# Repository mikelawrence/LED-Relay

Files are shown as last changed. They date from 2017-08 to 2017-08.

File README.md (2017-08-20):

# LED Relay Replacement PCB
This board was designed to act as a relay for multi-color strip LED lighting on my wife's Harley Tri Glide. The Infineon BTS7008 Dual High-Side Switch provides up to 7.5A per channel. The software allows a quick on-off-on sequence that keeps the LEDs lit after the trike is turned off for a programmable delay time in minutes. In addition to the Stay ON sequence the board also allows programming the amount of time to delay time. Set main.c for instructions on how to issue Stay ON sequence.

There are 4 inputs to the LED Relay board:
* +12V - This should be connected through a fuse to the battery and should remain hot even when the trike is off. All power to the outputs comes from this wire.
* ACC1 - This is +12V when the bike is turned on (ignition).
* ACC2 - This is +12V when the LED lights should be on.
* GND - Chassis and negative terminal of the battery.
The current software turns both outputs on when both ACC1 and ACC2 are at +12V but this can easily be changed to two independent outputs each controlled by its own ACC input. When either ACC1 off the micro-controller enters a low power state waiting for ACC1 to go back to +12V. Note with my current setup ACC2 can never go to +12V without ACC1 also going to +12V.

## Status and Testing
* Rev 2.2 PCB has not been ordered or tested. Since there is only one simple change and my Rev 2.1 was modified to Rev 2.2 I feel confident Rev 2.2 is ready for use.
  * Added ACC1 connection to PD2 on micro-controller. Only PIN2 has full asynchronous edge detection needed for ACC1.
  * You can order parts from Mouser using this [shared BOM](http://www.mouser.com/ProjectManager/ProjectDetail.aspx?AccessID=7477630473). Note LT3014 is not available at Mouser you must get it somewhere else like Digikey.
  * You can order the PCB from OSH Park using this [link](https://oshpark.com/shared_projects/Q2hSPIYz) to OSH Park.
* Rev 2.1 PCB has been ordered from OSH Park, assembled, and tested.
  * Added R12 and R13.
  * Moved ACC connections on micro-controller.
  * Testing complete after modifying to Rev 2.2.
* Rev 2.0 PCB.
  * Converted older design to KiCad.
  * Switched from low-side switch to dual high-side switch.
* Rev 1.0 Existed as another design that was close.

## Board Preview
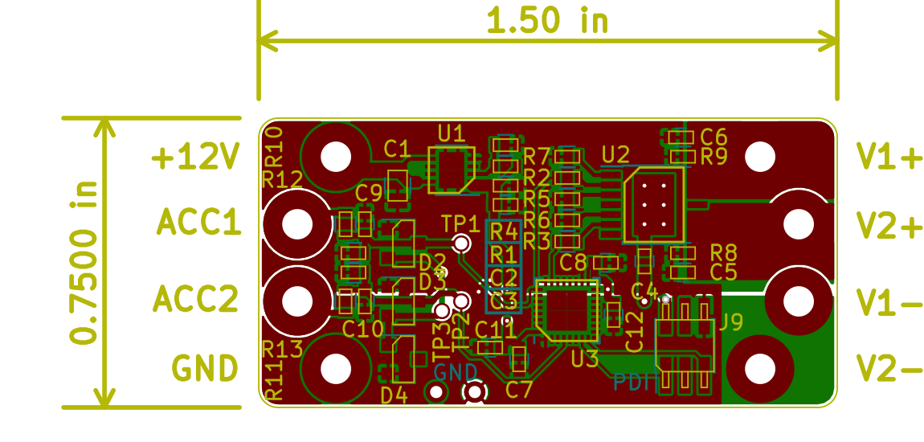
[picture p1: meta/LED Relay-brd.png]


## Notes
* The current usage is only one channel with a typical 4A LED load and maximum of 6A. I have not done any load testing to see how well the board operates with both channels going full bore. The High-Side Switch will shutdown to protect itself if it get too hot.
* When ACC1 is off the XMega8E5 enters an ultra low power mode drawing about 1µA. Add that to the LT3014 linear regulator's quiescent current and this board has standby current of 8µA. In bench testing my first board used 7.8µA at room temperature. Keep in mind this current is likely to double or even triple at higher temperatures but for a motorcycle or car battery this standby current is excellent.
* JP1 must be in place for circuit to work correctly. JP1 is a good scope ground point in testing.
* Assembling the this PCB will require a reflow oven. If you don't have one [Whizoo](http://www.whizoo.com/) sells a nice kit to make your own.
* PCB is designed in [KiCad](http://kicad-pcb.org) which is a great free EDA toolset.

## Software
The microcontroller is a Atmel/Microchip XMega8E5. Software is written in C using the free [Atmel Studio 7](https://www.google.com/search?q=atmel+studio+7). I recommend the Atmel ICE to both debug and program the XMega. Especially since it already has a 50mil PDI connector to plug directly onto the LED Relay board.

## Protection Against the Elements
When mounting on a motorcycle protection against the elements is crucial to longevity so the LED Relay board is thin enough to get 1" adhesive heat shrink on it. Once shrunk the board is well protected and the wires also get some strain relief.

Note I used several different sizes of adhesive heat shrink to get a watertight seal around the wires.
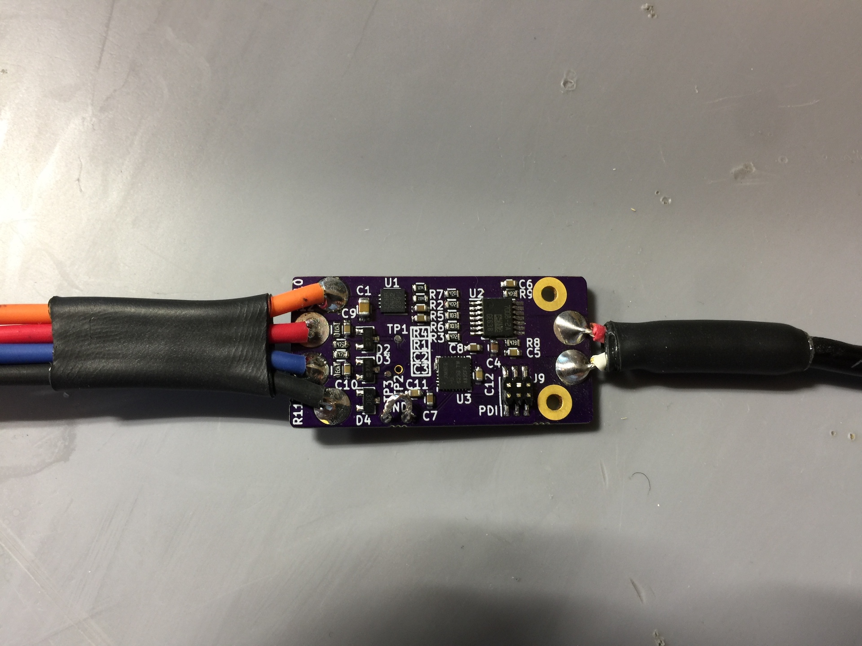
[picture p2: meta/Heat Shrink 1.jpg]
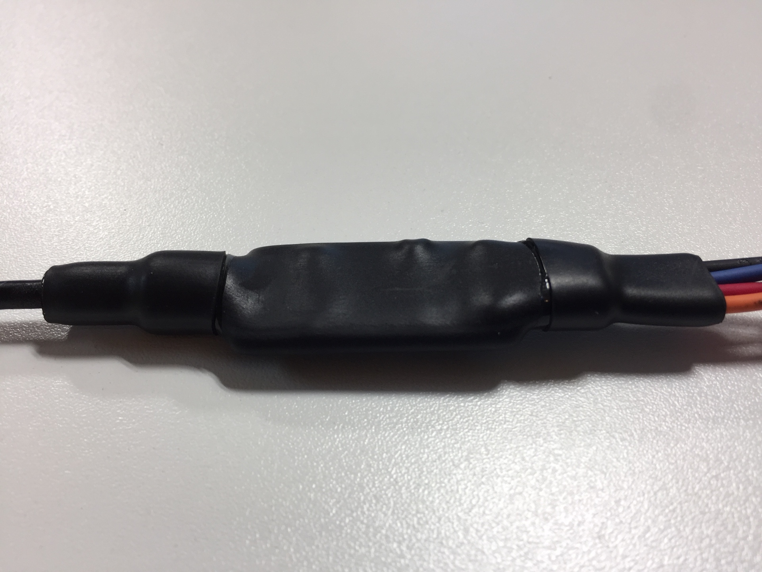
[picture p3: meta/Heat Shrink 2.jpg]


## Final Result
Here is the obligatory end result picture!
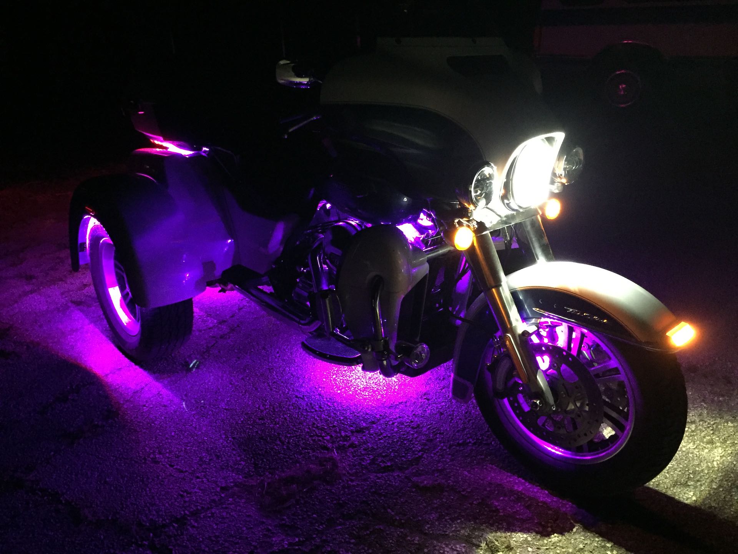
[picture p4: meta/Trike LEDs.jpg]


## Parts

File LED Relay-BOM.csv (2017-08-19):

Qty | Reference | Value | Package | Part Number | Manufacturer | Vendor | Vendor Part Number
6 | C5-C6, C9-C10, C11-C12 | 10nF | 603 | GCM188R72A103KA7D | Murata Electronics | Mouser | 81-GCM188R72A103KA7D
1 | C4 | 68nF | 603 | GCJ188R92A683KA01D | Murata Electronics | Mouser | 81-GCJ188R92A683KA1D
4 | C2-C3, C7-C8 | 0.47uF | 603 | GRM188R71C474KA88 | Murata Electronics | Mouser | 81-GRM188R71C474KA88
1 | C1 | 1uF | 805 | GRJ21BC72A105KE11L | Murata Electronics | Mouser | 81-GRJ21BC72A105KE1L
1 | R7 | 47 | 603 | RC0603FR-0747RL | Yageo | Mouser | 603-RC0603FR-0747RL
2 | R2-R3 | 4.7k | 603 | RC0603JR-074K7L | Yageo | Mouser | 603-RC0603JR-074K7L
2 | R5-R6 | 10k | 603 | RC0603JR-0710KL | Yageo | Mouser | 603-RC0603JR-0710KL
6 | R8-R9, R10-R13 | 47k | 603 | 603-RC0603JR-0747KL | Yageo | Mouser | 603-RC0603JR-0747KL
1 | R4 | 1.27M | 603 | CRCW06031M27FKEA | Vishay | Mouser | 71-CRCW06031M27FKEA
1 | R1 | 2.15M | 603 | CRCW06032M15FKEA | Vishay | Mouser | 71-CRCW06032M15FKEA
2 | D2-D3 | BAT54S | SOT-23 | BAT54S | Nexperia | Mouser | 771-BAT54S-T/R
1 | D1 | SM15T33CA | SMC | SM15T33CA | ST | Mouser | 511-SM15T33CA
1 | D4 | ZRC330 | SOT-23 | ZRC330F01TA | Diodes Inc. | Mouser | 522-ZRC330F01TA
1 | U3 | ATXMEGA8E5-M4U | QFN-32-1EP | ATXMEGA8E5-M4U | Atmel | Mouser | 556-ATXMEGA8E5-M4U
1 | U2 | BTS7008-2EPA | PG-TSDSO-14-22 | BTS70082EPAXUMA1 | Infineon | Mouser | 726-BTS70082EPAXUMA1
1 | U1 | LT3014IDD | DFN-8-1EP | LT3014BHVIDD#PBF | Linear Tech | Digikey | LT3014BHVIDD#PBF-ND
1 | J9 | Header | 6-Pin Header | 20021121-00006C4LF | Amphenol/FCi | Mouser | 649-202112100006C4LF

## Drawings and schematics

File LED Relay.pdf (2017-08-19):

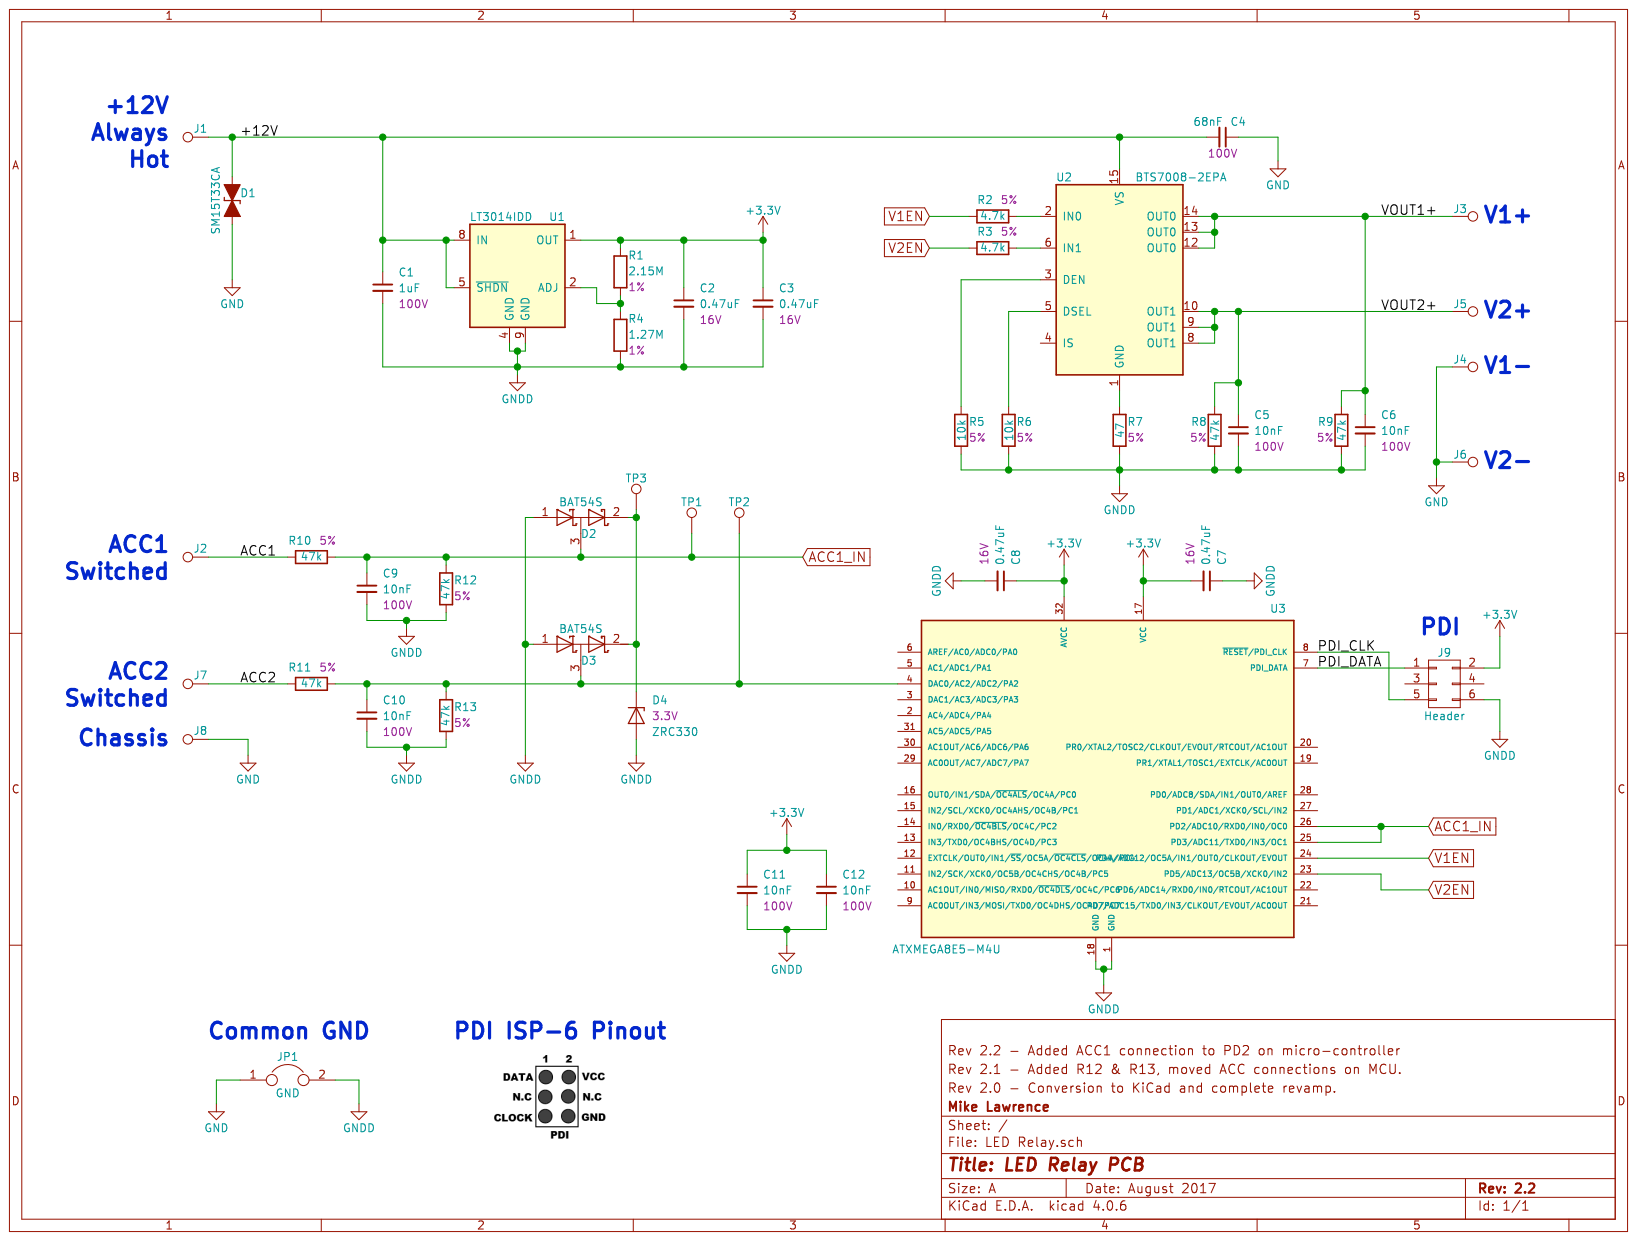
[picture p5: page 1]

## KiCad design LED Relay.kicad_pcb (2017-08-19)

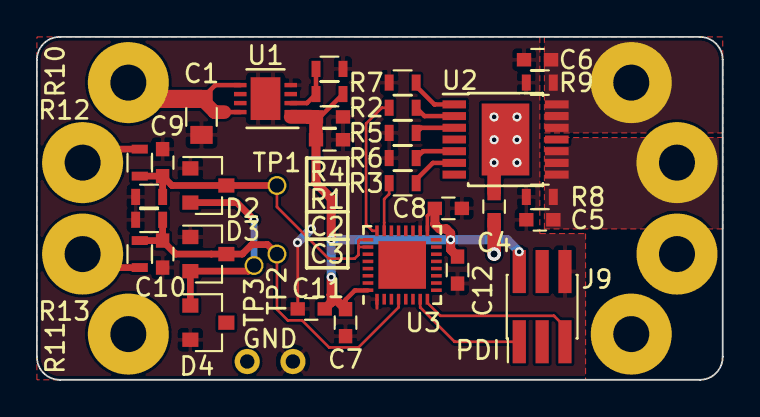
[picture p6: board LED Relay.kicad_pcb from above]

Board: 2 copper layers, 38.1 x 19.1 mm, 45 parts (1 on the bottom side), 21 nets.

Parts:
C1: 1uF; C_0805
C2, C3, C7, C8: 0.47uF; C_0603
C4: 68nF; C_0603
C5, C6, C9, C10, C11, C12: 10nF; C_0603
D1: SM15T33CA; D_SMC_Handsoldering
D2, D3: BAT54S; SOT-23
D4: ZRC330; SOT-23
J1, J2, J3, J4, J5, J6, J7, J8: TEST_1P; SolderWirePad_single_2mmDrill
J9: Header; Pin_Header_Straight_2x03_Pitch1.27mm_SMD
JP1: GND; WireConnection_0.80mmDrill_ThinPad
R1: 2.15M; R_0603
R2, R3: 4.7k; R_0603
R4: 1.27M; R_0603
R5, R6: 10k; R_0603
R7: 47; R_0603
R8, R9, R10, R11, R12, R13: 47k; R_0603
TP1, TP2, TP3: TEST_1P; SolderWirePad_single_0-8mmDrill
U1: LT3014IDD; DFN-8-1EP_3x3mm_Pitch0.5mm
U2: BTS7008-2EPA; Infineon_PG-TSDSO-14-22
U3: ATXMEGA8E5-M4U; QFN-32-1EP_4x4mm_Pitch0.4mm

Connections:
+3V3: C2.1, C3.1, C7.2, C8.1, C11.1, C12.1, J9.2, R1.2, U1.1, U3.17, U3.32
/+12V: C1.1, C4.2, D1.1, J1.1, U1.5, U1.8, U2.15
/ACC1: J2.1, R10.2
/ACC2: J7.1, R11.2
/PDI_CLK: J9.5, U3.8
/PDI_DATA: J9.1, U3.7
/VOUT1+: C6.1, J3.1, R9.2, U2.12, U2.13, U2.14
/VOUT2+: C5.1, J5.1, R8.2, U2.8, U2.9, U2.10
ACC1_IN: C9.1, D2.3, R10.1, R12.2, TP1.1, U3.25, U3.26
GND: C4.1, D1.2, J4.1, J6.1, J8.1, JP1.1
GNDD: C1.2, C2.2, C3.2, C5.2, C6.2, C7.1, C8.2, C9.2, C10.2, C11.2, C12.2, D2.1, D3.1, D4.2, J9.6, JP1.2, R4.1, R5.1, R6.1, R7.1, R8.1, R9.1, R12.1, R13.1, U1.4, U1.9, U3.1, U3.18
unnamed: C10.1, D3.3, R11.1, R13.2, TP2.1, U3.4
unnamed: D2.2, D3.2, D4.1, TP3.1
unnamed: R1.1, R4.2, U1.2
unnamed: R2.1, U2.2
unnamed: R3.1, U2.6
unnamed: R5.2, U2.3
unnamed: R6.2, U2.5
unnamed: R7.2, U2.1
V1EN: R2.2, U3.24
V2EN: R3.2, U3.23

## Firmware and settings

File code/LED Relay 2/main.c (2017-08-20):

/*
 * LED Relay 2.c
 *
 *  The any edge triggered input sense interrupt for ACC1 or ACC2 causes the de-bounce timer to be reset.
 *  Any time this interrupt occurs the input is considered ON which will allow a noisy ON to be recognized 
 *  as ON immediately. If the de-bounce timeout occurs then either the input has stabilized ON or OFF and
 *  and the de-bounce will evaluate the state.
 * Created: 8/12/2017 6:58:33 AM
 * Author : Mike Lawrence
 */ 

/*
 * Stay On sequence = ACC2 ON for less than 3 seconds, ACC2 OFF for less than 3 seconds, ACC1 ON.
 *   Next Power OFF the relay will remain on for programmed timeout (default 30 minute).
 *   This must be done for each power off cycle you want the Outputs to remain on.
 */

/*
 * Programming sequence (Only works within the first 60 seconds of ACC1 turning ON)
 * Flash sequence = ACC2 ON Pulse OFF each less than 3 seconds. The number of ACC2 pulses represents the 
 *   number of 10 minute increments to stay on after power off. The range is 1 to 25 increments or 10 - 250 minutes.
 * Program sequence = ACC2 OFF for 4 to 7 seconds after last flash ACC2 ON, ACC2 ON for 4 to 7 seconds, ACC2 OFF for 4 to 7 seconds, ACC2 ON.
 *
 * Example: Program 20 minute stay on after power OFF. 
 *
 *   ACC2 ON for 1 sec, ACC2 OFF for 1 sec, ACC2 ON for 1 sec, ACC2 OFF for 5 sec, ACC2 ON for 5 sec, ACC2 OFF for 5 sec, ACC2 ON.
 *   {    Flash 1     }                    {    Flash 2     }  {   1st Prog OFF  } {   1st Prog ON  } {   2nd Prog OFF  } { Prog Complete }
 *
 */
#include <avr/io.h>
#include <avr/interrupt.h>
#include <avr/eeprom.h>
#include <avr/sleep.h>
#include <avr/wdt.h>
#include "math.h"

/*
 * Fuse definitions
 */
FUSES =
{
	// FuseByte 1 = Watchdog timeouts set to 1,000 clocks or 1 s
	.FUSEBYTE1 = 0xFF & (~NVM_FUSES_WDWP_gm | WDWP_1KCLK_gc) & (~NVM_FUSES_WDP_gm | WDP_1KCLK_gc),	
	// FuseByte 2 = Application reset vector enabled, BOD is sampled in Power Down Mode
	.FUSEBYTE2 = 0xFF & (~NVM_FUSES_BOOTRST_bm | BOOTRST_APPLICATION_gc) & (~NVM_FUSES_BODPD_gm | BODPD_SAMPLED_gc),		
	// FuseByte 4 = Ext Reset is not disabled, Start Up Time is 0 ms, Watchdog timer is not locked 
	.FUSEBYTE4 = 0xFF & /* FUSE_RSTDISBL & */ (~NVM_FUSES_SUT_gm | SUT_0MS_gc) /* FUSE_WDLOCK */,							
	// FuseByte 5 = BOD continuous in Active Modes, EEPROM saved during chip erase, BOD Level is 2.0V
	.FUSEBYTE5 = 0xFF & (~NVM_FUSES_BODACT_gm | BODACT_CONTINUOUS_gc) & FUSE_EESAVE & (~NVM_FUSES_BODLVL_gm | BODLVL_2V0_gc), 
	// FuseByte 5 = Timer fault and detection defaults
	.FUSEBYTE6 = 0xFF,							
};

/*
 * Application specific definitions
 */
#define FALSE							0
#define TRUE							1
#define OFF								FALSE
#define ON								TRUE
#define DEFAULT_WAIT_MINUTES			30
#define WAIT_SECONDS					4
#define DEBOUNCE_TIME					0.050
#define WATCHDOG_TO						WDTO_2S
#define V12EN_port						PORTD
#define V1EN_bp							PIN4_bp
#define V2EN_bp							PIN5_bp
#define ACC1_port						PORTD
#define ACC1_bp							PIN2_bp
#define ACC2_port						PORTA
#define ACC2_bp							PIN2_bp
/*
 * Inferred definitions
 */
#define V1EN_ON()						V12EN_port.OUTSET = _BV(V1EN_bp)
#define V1EN_OFF()						V12EN_port.OUTCLR = _BV(V1EN_bp)
#define V2EN_ON()						V12EN_port.OUTSET = _BV(V2EN_bp)
#define V2EN_OFF()						V12EN_port.OUTCLR = _BV(V2EN_bp)
#define V12EN_ON()						V12EN_port.OUTSET = (_BV(V1EN_bp) | _BV(V2EN_bp))
#define V12EN_OFF()						V12EN_port.OUTCLR = (_BV(V1EN_bp) | _BV(V2EN_bp))
#define IS_ACC1_ON()					(ACC1_port.IN & _BV(ACC1_bp))
#define IS_ACC2_ON()					(ACC2_port.IN & _BV(ACC2_bp))
#define MAIN_TCNT_FROM_SECONDS(sec)		(uint16_t) round(sec / 0.001)


/*
 * Enumerations
 */
enum POWER_SM  { SM_POWER_RESET = 0, SM_POWER_DOWN, SM_POWER_OUT_OFF, SM_POWER_OUT_ON, SM_POWER_OUT_STAY_ON, SM_POWER_TIMER };
enum STAYON_SM { SM_STAYON_RESET = 0, SM_STAYON_WAIT_ON, SM_STAYON_WAIT_OFF};
enum PROG_SM   { SM_PROG_RESET = 0, SM_PROG_FLASH_ON, SM_PROG_FLASH_OFF, SM_PROG_END_ON, SM_PROG_END_OFF, SM_PROG_IND_ON, SM_PROG_IND_OFF };

/* 
 * EEPROM variables
 */
uint8_t EEMEM eeprom_wait_minutes = DEFAULT_WAIT_MINUTES;

/*
 * Global variables (Note best code optimization (code size) requires all defaults to be 0)
 */
volatile uint8_t  seconds = 0;						// Seconds counter
volatile uint8_t  minutes = 0;						// minutes counter

volatile uint8_t  acc1_debounce = 0;
volatile uint8_t  acc1_last;						// Last ACC1 state
volatile uint16_t acc1_on_start_time = 0;			// The value of Main Timer Count when ACC1 ON started
volatile uint16_t acc1_off_start_time = 0;			// The value of Main Timer Count when ACC1 OFF started

volatile uint8_t  acc2_debounce = 0;
volatile uint8_t  acc2_last;						// Last ACC2 state
volatile uint16_t acc2_on_start_time = 0;			// The value of Main Timer Count when ACC2 ON started
volatile uint16_t acc2_off_start_time = 0;			// The value of Main Timer Count when ACC2 OFF started

int main(void)
{
	uint8_t  power_state = SM_POWER_RESET;			// Current power state
	uint8_t  stayon_state = SM_STAYON_RESET;		// Current sequence state
	uint8_t  prog_state = SM_PROG_RESET;			// Current programming state
	uint8_t  wait_minutes;							// Number of minutes to stay on
	uint16_t acc1_on_time = 0;						// ACC1 length of time on
	uint16_t acc1_off_time = 0;						// ACC1 length of time off
	uint16_t acc2_on_time = 0;						// ACC2 length of time on
	uint16_t acc2_off_time = 0;						// ACC2 length of time off
	uint16_t tick_cnt_ms;							// Current time in ms (max 65.535 seconds)
	uint8_t  flash_count = 0;						// The number of valid program flashes received on ACC2
	
	// Disable the Watchdog timer on start
	wdt_disable();
    // main loop forever
    while (TRUE) 
    {
		// Each loop of main reset the Watchdog timer
		wdt_reset();
		// Compute most recent OFF and ON times
		cli();													// Disable interrupts before grabbing TCC4 count
		tick_cnt_ms = TCC4.CNT;									// Get the current tick_cnt
		if (acc1_last)
		{
			// ACC1 is currently ON so compute ON time
			acc1_on_time = tick_cnt_ms - acc1_on_start_time;	// ACC1 ON time in ms
			if (acc1_on_time > MAIN_TCNT_FROM_SECONDS(65.0))
			{
				// ACC1 ON time is too long
				acc1_on_time = MAIN_TCNT_FROM_SECONDS(65.0);	// ON time is restricted to 65.000 seconds
				acc1_on_start_time = tick_cnt_ms - MAIN_TCNT_FROM_SECONDS(65.0); // Adjust acc1_on_start_time
			}
		}
		else
		{
			// ACC1 is currently OFF so compute OFF time
			acc1_off_time = tick_cnt_ms - acc1_off_start_time;	// ACC1 OFF time in ms
			if (acc1_off_time > MAIN_TCNT_FROM_SECONDS(65.0))
			{
				// ACC1 OFF time is too long
				acc1_off_time = MAIN_TCNT_FROM_SECONDS(65.0);	// OFF time is restricted to 65.000 seconds
				acc1_off_start_time = tick_cnt_ms - MAIN_TCNT_FROM_SECONDS(65.0); // Adjust acc1_off_start_time
			}
		}
		if (acc2_last)
		{
			// ACC2 is currently ON so compute ON time
			acc2_on_time = tick_cnt_ms - acc2_on_start_time;	// ACC2 ON time in ms
			if (acc2_on_time > MAIN_TCNT_FROM_SECONDS(65.0))
			{
				// ACC2 ON time is too long
				acc2_on_time = MAIN_TCNT_FROM_SECONDS(65.0);	// ON time is restricted to 65.000 seconds
				acc2_on_start_time = tick_cnt_ms - MAIN_TCNT_FROM_SECONDS(65.0); // Adjust acc2_on_start_time
			}
		}
		else
		{
			// ACC2 is currently OFF so compute OFF time
			acc2_off_time = tick_cnt_ms - acc2_off_start_time;	// ACC2 OFF time in ms
			if (acc2_off_time > MAIN_TCNT_FROM_SECONDS(65.0))
			{
				// ACC2 OFF time is too long
				acc2_off_time = MAIN_TCNT_FROM_SECONDS(65.0);	// OFF time is restricted to 65.000 seconds
				acc2_off_start_time = tick_cnt_ms - MAIN_TCNT_FROM_SECONDS(65.0); // Adjust acc2_off_start_time
			}
		}
		sei();													// Enable interrupts

		// Power State Machine
		//   Manages initialization and the Power Switches
		switch (power_state)
		{
		case SM_POWER_DOWN:							// Board is Powered Down, Output is OFF, waiting for ACC1 turn ON
			V12EN_OFF();							// The power switches are OFF
			// See if ACC1 has switched ON
			if (acc1_last)
			{
				// ACC1 is now ON, what state we goto is dependent on ACC2
				if (acc2_last)
				{
					// ACC2 is ON
					power_state = SM_POWER_OUT_ON;	// Switch to Output ON state
				}
				else
				{
					// ACC2 is OFF
					power_state = SM_POWER_OUT_OFF;	// Switch to Output OFF state
				}
			}
			else
			{
				// ACC1 is still OFF, so enter Power Down State
				wdt_disable();						// Disable the watchdog timer before going to sleep
				set_sleep_mode(SLEEP_SMODE_PDOWN_gc); // Set Power Down Mode when sleep is executed
				sleep_mode();						// Enter Power Down State now
				wdt_enable(WATCHDOG_TO);			// Enable the Watchdog timer
				continue;							// We were woken from Power Down state, restart the while(TRUE) loop
			}
			break;
		case SM_POWER_OUT_OFF:						// Board is ON, Output is OFF (ACC1 is ON, ACC2 is OFF)
			V12EN_OFF();							// The power switches are OFF
			// See if ACC1 has switched OFF
			if (!acc1_last)
			{
				// ACC1 is now OFF
				power_state = SM_POWER_DOWN;		// Switch to Power Down State
			}
			else
			{
				// ACC1 is still ON, See if ACC2 has switched ON
				if (acc2_last)
				{
					// ACC2 is now ON
					power_state = SM_POWER_OUT_ON;	// Switch to Output On State
				}
			}
			break;
		case SM_POWER_OUT_ON:						// Board is ON, Output is ON (ACC1 is ON, ACC2 is ON)
			if (prog_state == SM_PROG_IND_OFF)
			{
				// The power switches are always OFF when Programming State is in Programming Success Output OFF state
				//  Handy indicator of programming success
				V12EN_OFF();						// The power switches are OFF
			}
			else
			{
				// Normal operation of Power Switches
				V12EN_ON();							// The power switches are ON				
			}
			// See if ACC1 has switched OFF
			if (!acc1_last)
			{
				// ACC1 is now OFF
				power_state = SM_POWER_DOWN;		// We need to power down
			}
			else
			{
				// ACC1 is still ON, See if ACC2 has switched OFF
				if (!acc2_last)
				{
					// ACC2 is now OFF
					power_state = SM_POWER_OUT_OFF;	// Switch to Output Off State
				}
			}
			break;
		case SM_POWER_OUT_STAY_ON:					// Board is ON, Output is ON (ACC1 is ON, ACC2 is ON)
			if (prog_state == SM_PROG_IND_OFF)
			{
				// The power switches are always OFF when Programming State is in Programming Success Output OFF state
				//  Handy indicator of programming success
				V12EN_OFF();						// The power switches are OFF
			}
			else
			{
				// Normal operation of Power Switches
				V12EN_ON();							// The power switches are ON				
			}
			// See if ACC1 has switched OFF
			if (!acc1_last)
			{
				// ACC1 is now OFF
				power_state = SM_POWER_TIMER;		// We need to enter Timer State
				cli();								// Disable interrupts
				minutes = 0; seconds = 0;			// Clear minutes and seconds
				TCC4.CCC = TCC4.CNT + MAIN_TCNT_FROM_SECONDS(1.0); // TCC4-CCC interrupt 1 second from now
				sei();								// Enable interrupts
			}
			else
			{
				// ACC1 is still ON, See if ACC2 has switched OFF
				if (!acc2_last)
				{
					// ACC2 is now OFF
					//  Make sure ACC2 OFF time is longer than 0.5 seconds before switching states
					//  This will allow ACC2 to turn off up to 0.5 seconds before ACC1 and
					//   still be recognized as Power Stay ON
					if (acc2_off_time > MAIN_TCNT_FROM_SECONDS(0.5))
					{
						power_state = SM_POWER_OUT_OFF;	// Switch to Output Off State
					}
				}
			}
			break;
		case SM_POWER_TIMER:						// ACC1 is OFF, Output is ON and waiting for timeout to occur
			V12EN_ON();								// The power switches are ON
			// See if ACC1 has switched ON
			if (acc1_last)
			{
				// ACC1 is now ON, what state we goto is dependent on ACC2
				if (acc2_last)
				{
					// ACC2 is ON
					power_state = SM_POWER_OUT_ON;	// Switch to Output ON state
				}
				else
				{
					// ACC2 is OFF
					power_state = SM_POWER_OUT_OFF;	// Switch to Output OFF state
				}
			}
			else
			{
				// ACC1 is still OFF, see if timeout has occurred
				cli();								// Disable interrupts
				if (minutes >= wait_minutes)
				{
					// Timeout has occurred
					sei();							// Re-enable interrupts
					power_state = SM_POWER_DOWN;	// Switch to Power Down State
				}
				else
				{
					// no timeout so go back to sleep for a while (second timer TCC4 will wake us up)
					sei();							// Re-enable interrupts
					wdt_disable();					// Disable the watchdog timer before going to sleep
					set_sleep_mode(SLEEP_SMODE_IDLE_gc); // Set Idle Mode when sleep is executed
					sleep_mode();					// Enter Idle Mode now, allow all interrupts
					//wdt_enable(WATCHDOG_TO);		// Enable the Watchdog timer
					continue;						// We were woken from Idle state, restart the while(TRUE) loop
				}
			}
			break;
		default:
			// Anything else is considered to SM_POWER_RESET
			cli();									// Disable interrupts
			// Clock defaults to internal 2MHz clock which is fine, but make sure 2MHz clock is ready before continuing
			while (!(OSC.STATUS & OSC_RC2MRDY_bm));
			// Initialize IOs, default all pins to input and have pull-ups enabled
			PORTA.DIRCLR = 0xFF;											// PORTA is all inputs
			PORTCFG.MPCMASK = 0xFF;
			PORTA.PIN0CTRL = PORT_OPC_PULLDOWN_gc | PORT_ISC_BOTHEDGES_gc;	// PORTA is all pullups
			PORTC.DIRCLR = 0xFF;											// PORTC is all inputs
			PORTCFG.MPCMASK = 0xFF;
			PORTC.PIN0CTRL = PORT_OPC_PULLDOWN_gc | PORT_ISC_BOTHEDGES_gc;	// PORTC is all pullups
			PORTD.DIRCLR = 0xFF;											// PORTD is all inputs
			PORTCFG.MPCMASK = 0xFF;
			PORTD.PIN0CTRL = PORT_OPC_PULLDOWN_gc | PORT_ISC_BOTHEDGES_gc;	// PORTD is all pullups
			PORTR.DIRCLR = 0xFF;											// PORTR is all inputs
			PORTCFG.MPCMASK = 0xFF;
			PORTR.PIN0CTRL = PORT_OPC_PULLDOWN_gc | PORT_ISC_BOTHEDGES_gc;	// PORTR is all pullups
			// Configure ACC1
			PORTCFG.MPCMASK = _BV(ACC1_bp) | _BV(3);
			ACC1_port.PIN0CTRL = PORT_OPC_TOTEM_gc | PORT_ISC_BOTHEDGES_gc;	// Input NO pullup and interrupt on any edge
			ACC1_port.INTCTRL = PORT_INTLVL_HI_gc;							// Interrupt will be high level
			ACC1_port.INTMASK |= _BV(ACC1_bp);								// Port interrupt enabled
			// Configure ACC2
			PORTCFG.MPCMASK = _BV(ACC2_bp);
			ACC2_port.PIN0CTRL = PORT_OPC_TOTEM_gc | PORT_ISC_BOTHEDGES_gc;	// Input NO pullup and interrupt on any edge
			ACC2_port.INTCTRL = PORT_INTLVL_HI_gc;							// Interrupt will be high level
			ACC2_port.INTMASK |= _BV(ACC2_bp);								// Port interrupt enabled
			// Configure V1EN and V2EN as totem-pole outputs
			V12EN_port.OUTCLR = _BV(V1EN_bp) | _BV(V2EN_bp);				// V1EN and V2EN will be low when enabled
			PORTCFG.MPCMASK = _BV(V1EN_bp) | _BV(V2EN_bp);
			V12EN_port.PIN0CTRL = PORT_OPC_TOTEM_gc;						// V1EN and V2EN will be totem-pole outputs
			V12EN_port.DIRSET = _BV(V1EN_bp) | _BV(V2EN_bp);				// V1EN and V2EN are now outputs
			// Configure Power Reduction
			PR.PRGEN = 1 << PR_XCL_bp				// XCL power down: enabled
					 | 1 << PR_RTC_bp				// RTC power down: enabled
					 | 0 << PR_EVSYS_bp				// EVSYS power down: disabled
					 | 1 << PR_EDMA_bp;				// EDMA power down: enabled
			PR.PRPA = 1 << PR_DAC_bp				// DACA power down: enabled
					| 1 << PR_ADC_bp				// ADCA power down: enabled
					| 1 << PR_AC_bp;				// ACA power down: enabled
			PR.PRPC = 1 << PR_TWI_bp				// TWIC power down: enabled
					| 1 << PR_USART0_bp				// USART0C power down: enabled
					| 1 << PR_SPI_bp				// SPIC power down: enabled
					| 1 << PR_HIRES_bp				// HIRESC power down: enabled
					| 0 << PR_TC5_bp				// TCC5 power down: disabled
					| 0 << PR_TC4_bp;				// TCC4 power down: disabled
			PR.PRPD = 1 << PR_USART0_bp				// USART0D power down: enabled
					| 1 << PR_TC5_bp;				// TDC5 power down: enabled
			// Configure 1ms tick on TCC5
			TCC5.PER = 1999;						// Period 1999 is 1 ms overflow
			TCC5.CTRLA = TC_CLKSEL_DIV1_gc			// Source is System Clock
					   | 0 << TC5_UPSTOP_bp			// Stop on Next Update: disabled
					   | 0 << TC5_EVSTART_bp		// Start on Next Event: disabled
					   | 0 << TC5_SYNCHEN_bp;		// Synchronization Enabled: disabled
			// Configure Event Channel 0 for TCC5 overflow
			EVSYS.CH0MUX = EVSYS_CHMUX_TCC5_OVF_gc; // Timer/Counter C5 Overflow
			// Configure main timer
			TCC4.CTRLA = TC_CLKSEL_EVCH0_gc			// Event Channel 0
					   | 0 << TC4_UPSTOP_bp			// Stop on Next Update: disabled
					   | 0 << TC4_EVSTART_bp		// Start on Next Event: disabled
					   | 0 << TC4_SYNCHEN_bp;		// Synchronization Enabled: disabled
			// Set interrupt level to high for TCC4-CCA, TCC4-CCB and TCC4-CCC
			TCC4.INTCTRLB = TC_CCAINTLVL_HI_gc		// CCA High level interrupt priority
						  | TC_CCBINTLVL_HI_gc		// CCB High level interrupt priority
						  | TC_CCCINTLVL_HI_gc		// CCC High level interrupt priority
						  | TC_CCDINTLVL_OFF_gc;	// CCD interrupt disabled
			// TCC4-CCC interrupt 1 second from now
			TCC4.CCC = TCC4.CNT + MAIN_TCNT_FROM_SECONDS(1.0);
			// Enable high level interrupts
			PMIC.CTRL = 0 << PMIC_RREN_bp			// Round-Robin Priority Enable: disabled
					  | 0 << PMIC_IVSEL_bp			// Interrupt Vector Select: disabled
					  | 1 << PMIC_HILVLEN_bp		// High Level Enable: enabled
					  | 0 << PMIC_MEDLVLEN_bp		// Medium Level Enable: disabled
					  | 0 << PMIC_LOLVLEN_bp;		// Low Level Enable: disabled
			// Get ACC1 current state
			if IS_ACC1_ON()
			{
				// ACC1 is currently on
				acc1_last = ON;						// Last ACC1 state is ON
				if IS_ACC2_ON()
				{
					// ACC1 and ACC2 are on
					power_state = SM_POWER_OUT_ON;	// Switch to Power Active State
				}
				else
				{
					// ACC1 is ON, ACC2 is OFF
					power_state = SM_POWER_OUT_OFF;	// Switch to Power Active State
				}
			}
			else
			{
				// ACC1 is currently off
				acc1_last = OFF;					// Last ACC1 state is OFF
				power_state = SM_POWER_DOWN;		// Switch to Power Down State
			}
			// Initialize variables
			seconds = 0;
			minutes = 0;
			// Read the wait minutes from EEPROM
			wait_minutes = eeprom_read_byte(&eeprom_wait_minutes);
			// Enable the Watchdog timer
			wdt_enable(WATCHDOG_TO);
			// Enable global interrupts
			sei();
			continue;								//  restart the main forever loop
		}
		// The StayON State Machine and Programming State Machines do not run when ACC1 is OFF
		if (!acc1_last) 
		{
			// ACC1 is OFF
			stayon_state = SM_STAYON_RESET;			// Reset the StayON State Machine
			prog_state = SM_PROG_RESET;				// Reset the Programming State Machine
			continue;								// Restart the while loop (this disables State Machines below this point)
		}
		// StayON State Machine
		//   Looks for a short sequence to keep the Outputs ON after bike is turned off
		switch (stayon_state)
		{
		case SM_STAYON_WAIT_ON:						// Waiting for ACC2 to turn ON (1st ON)
			if (acc2_on_time > MAIN_TCNT_FROM_SECONDS(3.0))
			{
				// ON time is longer than 3 seconds
				stayon_state = SM_STAYON_RESET;		// Reset the StayON State Machine
			}
			else
			{
				// ON time is less than 3 seconds
				if (!acc2_last)
				{
					// ACC2 turned OFF, we had a valid ON time
					stayon_state = SM_STAYON_WAIT_OFF; // Goto wait for 1st OFF time
				}
			}
			break;
		case SM_STAYON_WAIT_OFF:					// Waiting for ACC2 to turn OFF (1st OFF)
			if (acc2_off_time > MAIN_TCNT_FROM_SECONDS(3.0))
			{
				// OFF time is longer than 3 seconds
				stayon_state = SM_STAYON_RESET;		// Reset the StayON State Machine
			}
			else
			{
				// OFF time is less than 3 seconds
				if (acc2_last)
				{
					// ACC2 turned ON, this correctly identifies the StayON sequence
					stayon_state = SM_STAYON_RESET;	// Reset the StayON State Machine
					power_state = SM_POWER_OUT_STAY_ON; // Force the Power State Machine to Output Stay ON state
				}
			}
			break;
		default:									// All other states are considered SM_POWER_RESET
			// Do nothing if ACC1 is not ON
			if (acc1_last) 
			{
				// ACC2 turning ON will start the entire process
				if (acc2_last)
				{
					stayon_state = SM_STAYON_WAIT_ON; // Goto wait for ACC2 to turn OFF state
				}
			}
			break;
		}
		// Programming State Machine
		//   Looks for programming state based on ACC2 input
		switch (prog_state)
		{
		case SM_PROG_FLASH_ON:						// Waiting for ACC2 to turn OFF to capture an ON press for the flash count
			if (acc2_on_time > MAIN_TCNT_FROM_SECONDS(3.0))
			{
				// ACC2 ON time is longer than 3 seconds, this aborts flash the sequence
				prog_state = SM_PROG_RESET;			// Reset the Programming State Machine
			}
			else if (!acc2_last)
			{
				// ACC2 ON time is less than 3 seconds, this is a flash pulse
				++flash_count;						// Increment flash count
				prog_state = SM_PROG_FLASH_OFF;		// Goto wait for ACC2 to turn ON for flash OFF time
			}
			break;
		case SM_PROG_FLASH_OFF:						// Waiting for ACC2 to turn ON to capture an OFF time between ON presses
			if (acc2_off_time > MAIN_TCNT_FROM_SECONDS(7.0))
			{
				// ACC2 OFF time is longer than 7 seconds, this aborts the flash sequence
				prog_state = SM_PROG_RESET;			// Reset the Programming State Machine
			}
			else if (acc2_last)
			{
				// ACC2 OFF time is less than 7 seconds and ACC2 turned ON
				if (acc2_off_time > MAIN_TCNT_FROM_SECONDS(4.0))
				{
					// OFF time is between 4 and 7 seconds which ends the flash sequence and starts the program sequence
					prog_state = SM_PROG_END_ON;
				}
				else if (acc2_off_time > MAIN_TCNT_FROM_SECONDS(3.0))
				{
					// ACC2 OFF time is between 3 and 4 seconds, this aborts the flash sequence
					prog_state = SM_PROG_RESET;			// Reset the Programming State Machine
				}
				else
				{
					// ACC2 OFF time is less than 3 seconds and is valid off time, we are still flashing
					prog_state = SM_PROG_FLASH_ON;
				}
			}
			break;
		case SM_PROG_END_ON:						// Waiting for ACC2 to turn OFF to capture an ON press for the end sequence
			if (acc2_on_time > MAIN_TCNT_FROM_SECONDS(7.0))
			{
				// ACC2 OFF time is longer than 7 seconds, this aborts the end sequence
				prog_state = SM_PROG_RESET;			// Reset the Programming State Machine			
			}
			else if (!acc2_last)
			{
				// ACC2 ON time is less than 7 seconds and ACC2 turned OFF
				if (acc2_on_time > MAIN_TCNT_FROM_SECONDS(4.0))
				{
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

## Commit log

2017-08-19 Upped Rev to 2.1. Added R12 and R13. Moved connections on micro-controller.
    [LED Relay-BOM.csv, LED Relay.kicad_pcb, LED Relay.sch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]
2017-08-19 Upped Rev to 2.2. Added ACC1 connect to PD2 on micro-controller.
    [LED Relay.kicad_pcb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]
